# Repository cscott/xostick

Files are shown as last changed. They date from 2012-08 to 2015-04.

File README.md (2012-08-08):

This is a simple Open Hardware peripheral for the OLPC XO-1/1.5/1.75/4.

The files are created using Eagle 6.2.0 on Linux and the SparkFun
footprint libraries.

Some details about the design:

1. Supporting using either the ATtiny85 (lowest cost) or the ATtiny861
   (14 I/Os, slightly more expensive).
2. Based on the Sparkfun AVR Stick
    http://www.sparkfun.com/products/9147
   and thus software will be based on
    http://www.obdev.at/vusb/
   Note that the USB port has been moved to PB3/4 so software for the
   SparkFun AVR Stick will not work without modification.
3. The PCB we're working with is 0.8mm (0.031"); a USB plug "is supposed to be
   2.4mm (0.093") but you can get away with 1.6mm (0.062")" (thanks, djgpp)
   Our solution is to put two breakaway tabs on the back of the board.  You
   can break them off and glue them below the USB fingers to make it stay in
   the port better/at all.  One gotcha is that break away PCBs tend to stress
   nearby traces; I've tried to give them adequate clearance.  We're also
   putting copper fills on the PCBs to make them thicker (thanks again, djgpp).
   The PCB we have also has 4 layers, but I've routed this board with only
   the top and bottom so that 2 layer reproductions will work just fine as
   well.  The inner two layers are ground and power planes, which don't
   need to be present to connect the ground and power nets.
4. I'm attempting to bring BOM below $1/student and part count down as low as
   possible as well.  As a result, we're skimping a bit on ferrites and
   bypass caps.
5. There are pads for populating a mini USB B connector, so you can
   put this on a cable (and avoid the glue-the-PCBs-together dance).
6. The XO Stick has a standard arduino shield pinout.  This lets it be
   piggybacked on another XO Stick for programming, or piggy backed on
   an XOrduino to control a turtle robot.  Standard arduino shields will
   probably *not* work, since not all pins are connected -- but they might!
7. To program one XO Stick from an XOrduino, the RST header on the
   target should be put in the "PROG" position so that the programmer
   can drive it via arduino pin 0.  To program an XO Stick from another
   XO Stick, both RST headers should be in the "NORM" position, and
   the programmer needs to have the RSTDISBL fuse programmed, so that it
   can use PB5 ('85) or PB7 ('861) as an output.  Note that once RSTDISBL
   is programmed, the device can't be programmed using the ICSP port
   until RSTDISBL is unprogrammed using the high-voltage programming method.
8. The XO Stick currently needs an external programmer.
   Can we write a USB DFU bootloader using v-usb?
   Something like:

        http://www.obdev.at/products/vusb/usbasploader.html
        http://embedded-creations.com/projects/attiny85-usb-bootloader-overview/
        https://github.com/embedded-creations/USBaspLoader-tiny85

  -- C. Scott Ananian, 2012-06-09; revised 2012-07-30, 2012-08-08

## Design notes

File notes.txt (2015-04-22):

Notes on v14:
- LEDs should be labelled red/green in addition to LED1/LED2
- 10uF cap needs more space if XO Stick is to be used as shield
  (replaced with 6mm high cap in BOM, for $0.02 cost up)
- PROG/BOT header is too tight.  Vin header is ok?
- Vin and proto area vias should have larger pads
- pf says holes are in general too small for used parts.  make them
  all the same size as the proto area?
- measure tabs.  maybe too think now that there's solder resist and
  copper on it?
- add [outside] gnd, vcc, sig1, sig2 [inside] for mounting grove-style
  connectors? pgf wants [gnd, vcc, open] pattern somewhere for wiring
  connectors.

Notes on v9:
- usb connector up toward notch a little bit?  binding on bottom side.
  (moved 10 mil up for v10, chamfered bottom corner as well)

Notes on v5:

- ATtiny261A should be at least ATtiny461a if not ATtiny861a, since
  USB library takes up 2496 bytes.
- full size USB convert to mini or micro? (no through-hole micro-B connectors?)
- LED1/LED2 need better polarity mark
- use '-kit' suffixed versions of footprints (solder mask on component side)
- break off tab appears to work well.
- island between tabs should be anchored to body, not tabs?
- can we avoid anchors on break off tabs, instead use central anchor?
   ie.
     T
  ------------
 |            |
  --          \--
 TXT|            |
  --          \--
 |            |
  ------------
     T
where T indicates tabs.

- remove symmetry from USB connector placement to allow two tabs on
  XOrduino board.  (ie, move connector all the way down)
  (but retain 1.9" max width and spacing between USB port and edge to
  allow plugging XO Stick into vertical USB port on XO)

- J5/J6 should be normally-closed.

- EC programming header: 3.3v conversion (zeners?)
I was just looking at you pinout to check.  :)  Your pinout is close
but you don't have a chip select at all.  Its required for both the
EDI and talking to the SPI flash and there isn't a ground connection
in your pinout.

Look at the schematics in the dev docs cl4 directory. The same pinout
is used for both the EC EDI connection and the header for programming
the SPI flash.

Pin 1: MISO
Pin 2: Vcc (3.3V or NC for EC)
Pin 3: SCLK
Pin 4: MOSI
Pin 5: CS#
Pin 6: GND

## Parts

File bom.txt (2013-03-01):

Bill of Materials (v14)
Prices are from digikey, and in quantity 100.
---------------------------------------------

Required:
Part     Value            Device            Package              Library  DigiKey       Price (qty 100)
C1       10uF             CAP_POLPTH2       CPOL-RADIAL-10UF-25V SparkFun 493-5946-ND           $0.08020  (.06" lead spacing, 6mm tall)
C2       0.1uF            CAPPTH            CAP-PTH-SMALL        SparkFun 478-5741-ND           $0.09450 (.100" lead spacing)
D1       3V3              DIODE-ZENERPTH    DIODE-ZENER          SparkFun 1N5226BFSCT-ND        $0.072
D2       3V3              DIODE-ZENERPTH    DIODE-ZENER          SparkFun 1N5226BFSCT-ND        $0.072
R1       68               RESISTORAXIAL-0.3 AXIAL-0.3            SparkFun CF14JT68R0CT-ND	$0.02190 axial 0.3"
R2       68               RESISTORAXIAL-0.3 AXIAL-0.3            SparkFun CF14JT68R0CT-ND	$0.02190 axial 0.3"
R3       1.5K             RESISTORAXIAL-0.3 AXIAL-0.3            SparkFun CF14JT1K50CT-ND       $0.02190 axial 0.3"
U1       TINY85P          TINY85P           DIL08                atmel    ATTINY85-20PU-ND      $0.72 (instead of U2)
or
U2       TINY861A         TINY861P          DIL20                atmel    ATTINY861-20PU-ND     $1.75   (instead of U1)

Recommended I/O:
Part     Value            Device            Package              Library  DigiKey       Price (qty 100)
LED1     GREEN            LED3MM            LED3MM               SparkFun 754-1217-ND           $0.07150 3mm T1 green
LED2     RED              LED3MM            LED3MM               SparkFun 754-1218-ND           $0.07150 3mm T1 red
R4       470              RESISTORAXIAL-0.3 AXIAL-0.3            SparkFun CF14JT470RCT-ND       $0.02190 axial 0.3"
R5       470              RESISTORAXIAL-0.3 AXIAL-0.3            SparkFun CF14JT470RCT-ND       $0.02190 axial 0.3"
SW1      USER             TAC_SWITCHPTH     TACTILE-PTH          SparkFun 450-1652-ND           $0.1114  6mm

Optional:
Part     Value            Device            Package              Library  DigiKey       Price (qty 100)
H2       AVR_SPI_PRG_6PTH AVR_SPI_PRG_6PTH  2X3                  SparkFun 609-3218-ND           $0.1778
JP1/J1   RESET/POWER HEADER                 1x4, 1x4ish                   S1012EC-08-ND         $0.16950
U1 socket                                                                 AE9986-ND             $0.1196
U2 socket                                                                 AE9998-ND             $0.1911
X2 USB mini-B                                                             WM17115-ND            $1.1038
U3                                                                        497-7288-ND           $0.21000

Headers, to make a stackable or arduino-compatible board:

Part     Value       DigiKey      Price (qty 100)
H1       1x6         609-3558-ND  $0.6796
         1x8         609-3559-ND  $0.8791
         1x8         609-3559-ND  $0.8791
         1x10        609-3550-ND  $1.0657

(Note that digikey's prices for headers are quite steep.
SparkFun sells all four for $1.20 (quantity 100) at
  https://www.sparkfun.com/products/11417
which is substantially less than DigiKey, even though
SparkFun is selling at retail markup.  Presumably a large
deployment could get an even better wholesale price.
The DigiKey headers are also not stackable.)

----
Paste-able BOM for the required+recommended parts ('861 version):
(use https://ordering.digikey.com/registereduser/TextFileImport.aspx)

Required: (pick 1 of U1/U2)
1,493-5946-ND,C1 10uF
1,478-5741-ND,C2 0.1uF
2,1N5226BFSCT-ND,D1 D2 3.3V Zener
2,CF14JT68R0CT-ND,R1 R2 68 ohm
1,CF14JT1K50CT-ND,R3 1.5k ohm
1,ATTINY85-20PU-ND,U1
1,ATTINY861-20PU-ND,U2

Recommended:
1,754-1217-ND,LED1 T1 Green
1,754-1218-ND,LED2 T1 Red
2,CF14JT470RCT-ND,R4 R4 470 ohm
1,450-1652-ND,SW1 6mm

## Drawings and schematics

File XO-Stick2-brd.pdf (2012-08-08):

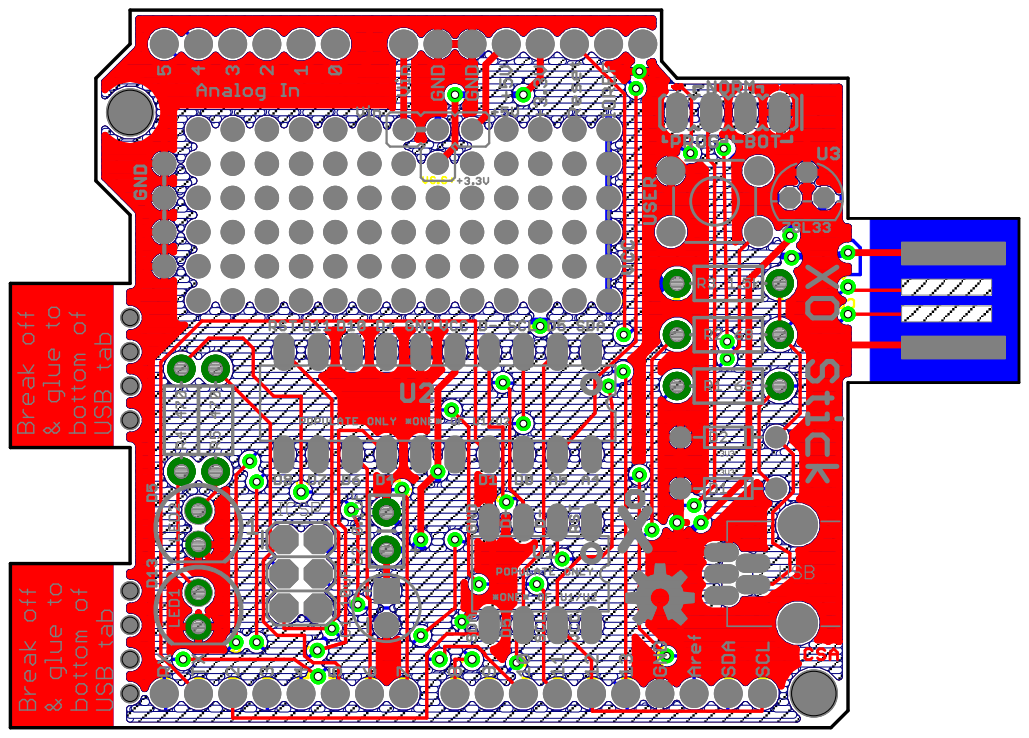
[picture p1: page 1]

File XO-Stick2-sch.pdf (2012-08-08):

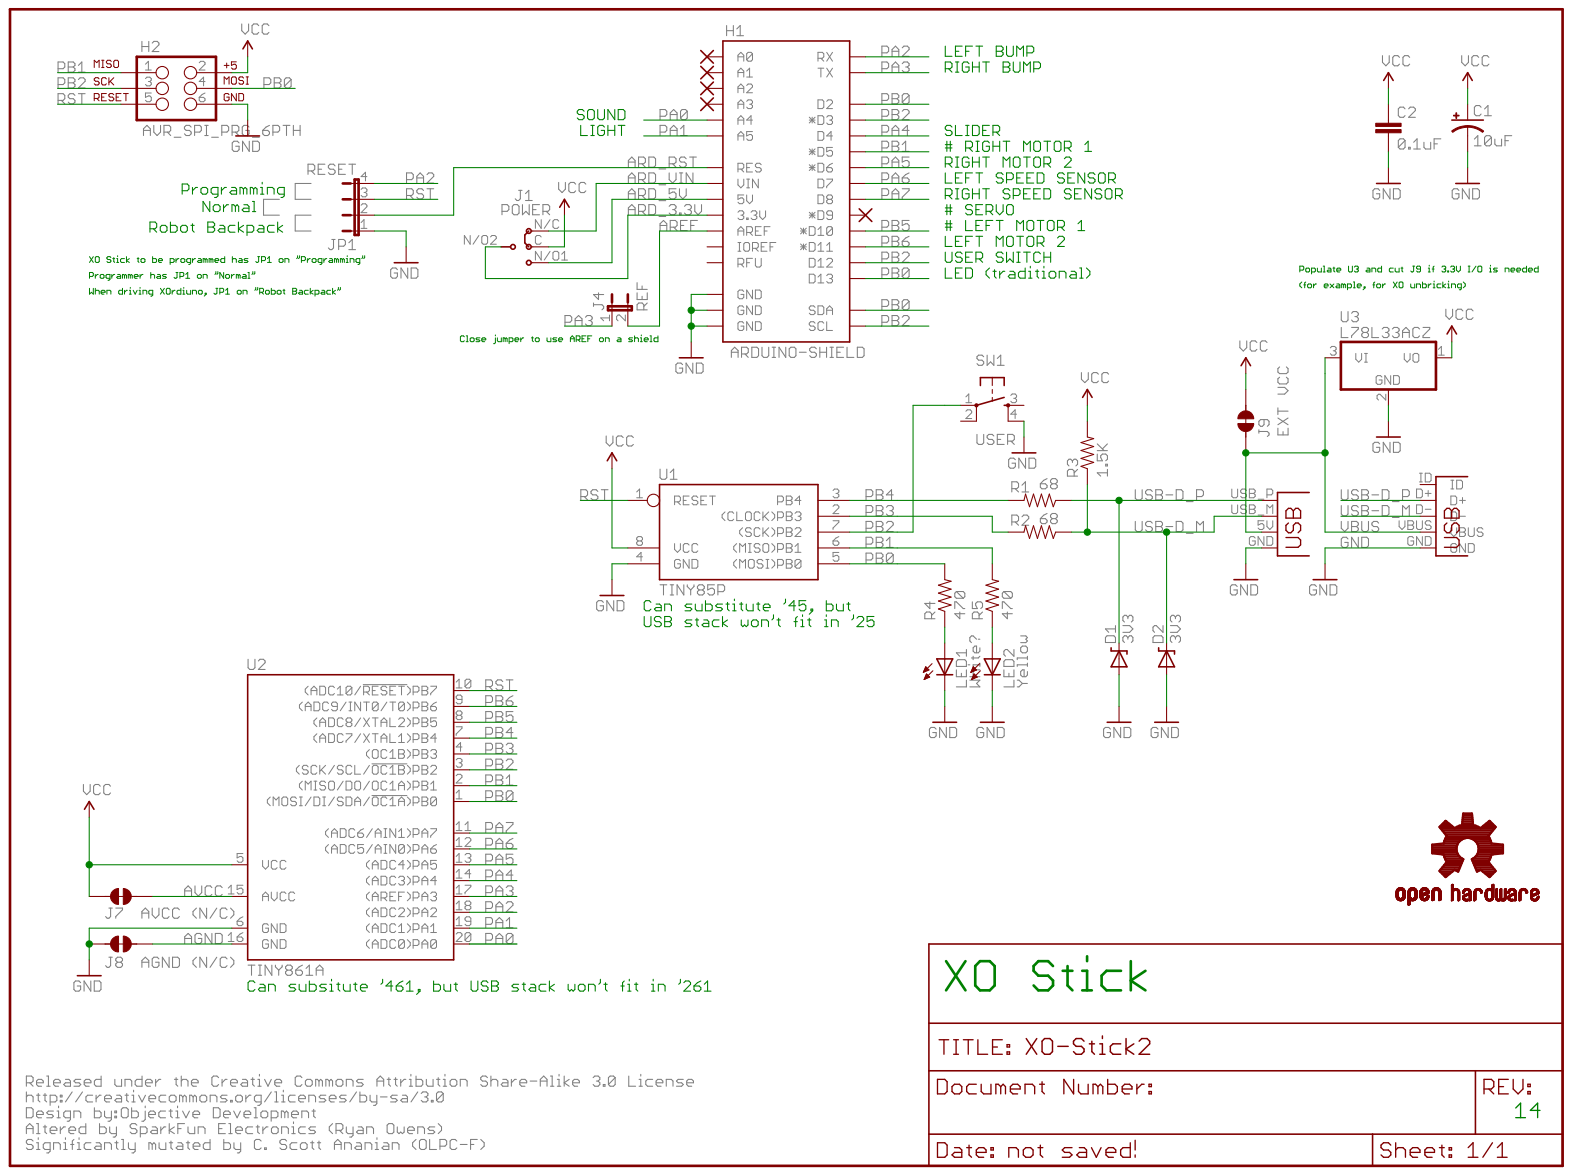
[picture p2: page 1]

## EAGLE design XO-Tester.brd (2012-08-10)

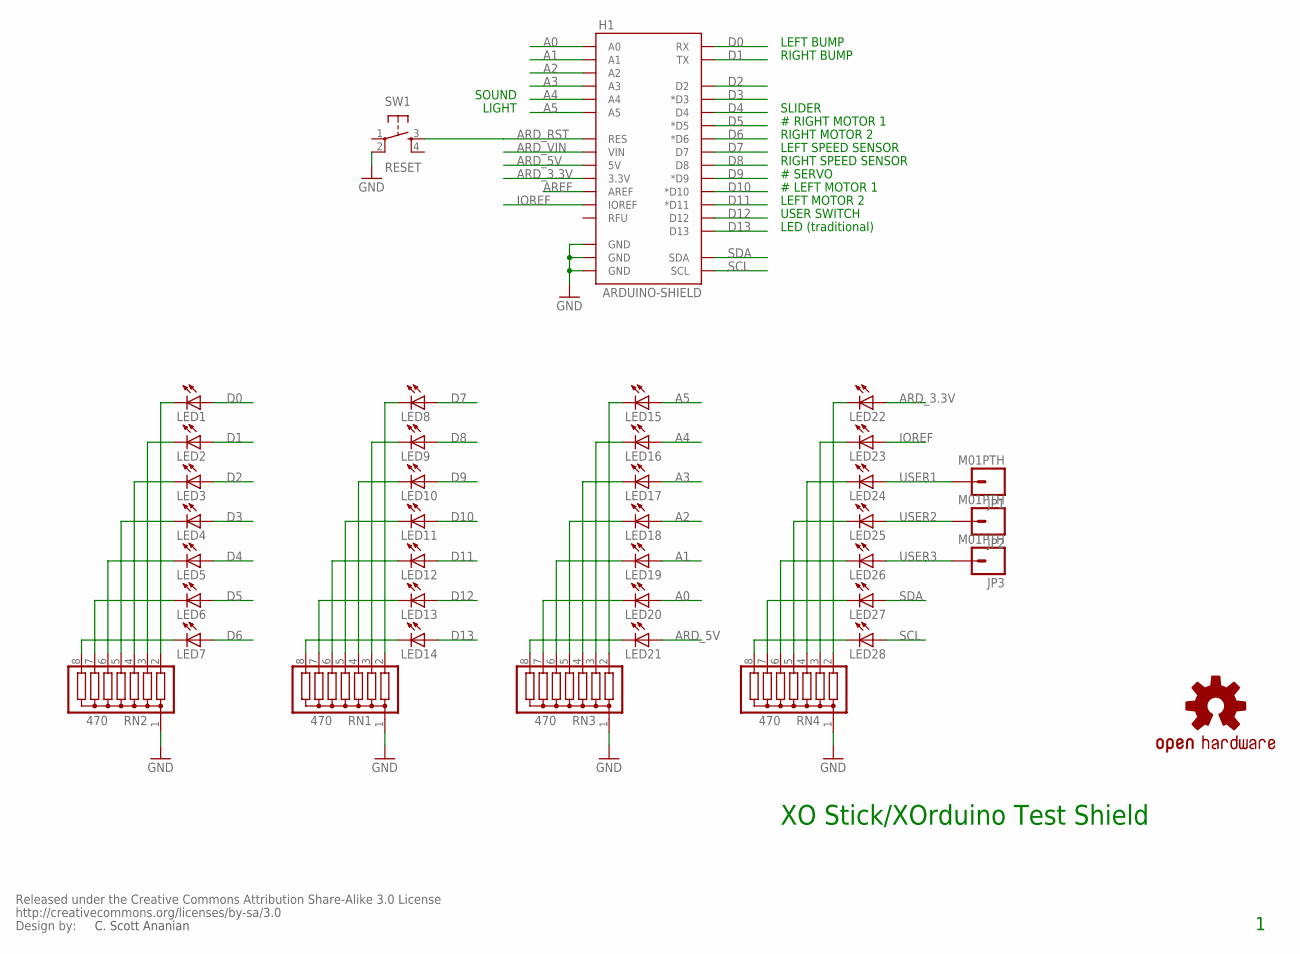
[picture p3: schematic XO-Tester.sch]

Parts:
H1: ARDUINO-SHIELD; ARDUINO-SHIELD-VIAS-HOLES
JP1, JP2, JP3: M01PTH; 1X01
LED1, LED2, LED3, LED4, LED5, LED6, LED7, LED8, LED9, LED10, LED11, LED12, LED13, LED14, LED15, LED16, LED17, LED18, LED19, LED20, LED21, LED22, LED23, LED24, LED25, LED26, LED27, LED28: LED3MM-KIT
RN1, RN2, RN3, RN4: 470; SIL8
SW1: RESET; TACTILE-PTH
U$1: OSHW-LOGOM; OSHW-LOGO-M
U$4: CREATIVE_COMMONS

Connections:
A0: H1.A0, LED20.A
A1: H1.A1, LED19.A
A2: H1.A2, LED18.A
A3: H1.A3, LED17.A
A4: H1.A4, LED16.A
A5: H1.A5, LED15.A
ARD_3.3V: H1.3.3V, LED22.A
ARD_5V: H1.5V, LED21.A
ARD_RST: H1.RES, SW1.3
ARD_VIN: H1.VIN
AREF: H1.AREF
D0: H1.RX, LED1.A
D1: H1.TX, LED2.A
D2: H1.D2, LED3.A
D3: H1.D3 (*D3), LED4.A
D4: H1.D4, LED5.A
D5: H1.D5 (*D5), LED6.A
D6: H1.D6 (*D6), LED7.A
D7: H1.D7, LED8.A
D8: H1.D8, LED9.A
D9: H1.D9 (*D9), LED10.A
D10: H1.D10 (*D10), LED11.A
D11: H1.D11 (*D11), LED12.A
D12: H1.D12, LED13.A
D13: H1.D13, LED14.A
GND: H1.GND@0 (GND), H1.GND@1 (GND), H1.GND@2 (GND), RN1.1, RN2.1, RN3.1, RN4.1, SW1.2
IOREF: H1.IOREF, LED23.A
unnamed: LED8.K (C), RN1.2
unnamed: LED9.K (C), RN1.3
unnamed: LED1.K (C), RN2.2
unnamed: LED2.K (C), RN2.3
unnamed: LED3.K (C), RN2.4
unnamed: LED4.K (C), RN2.5
unnamed: LED5.K (C), RN2.6
unnamed: LED6.K (C), RN2.7
unnamed: LED7.K (C), RN2.8
unnamed: LED10.K (C), RN1.4
unnamed: LED11.K (C), RN1.5
unnamed: LED12.K (C), RN1.6
unnamed: LED13.K (C), RN1.7
unnamed: LED14.K (C), RN1.8
unnamed: LED15.K (C), RN3.2
unnamed: LED16.K (C), RN3.3
unnamed: LED17.K (C), RN3.4
unnamed: LED18.K (C), RN3.5
unnamed: LED19.K (C), RN3.6
unnamed: LED20.K (C), RN3.7
unnamed: LED21.K (C), RN3.8
unnamed: LED22.K (C), RN4.2
unnamed: LED23.K (C), RN4.3
unnamed: LED24.K (C), RN4.4
unnamed: LED25.K (C), RN4.5
unnamed: LED26.K (C), RN4.6
unnamed: LED27.K (C), RN4.7
unnamed: LED28.K (C), RN4.8
SCL: H1.SCL, LED28.A
SDA: H1.SDA, LED27.A
USER1: JP1.1, LED24.A
USER2: JP2.1, LED25.A
USER3: JP3.1, LED26.A

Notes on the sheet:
C. Scott Ananian
XO Stick/XOrduino Test Shield
# RIGHT MOTOR 1
# SERVO
# LEFT MOTOR 1
LEFT BUMP
RIGHT BUMP
SLIDER
RIGHT MOTOR 2
LEFT SPEED SENSOR
RIGHT SPEED SENSOR
LEFT MOTOR 2
USER SWITCH
LED (traditional)
SOUND
LIGHT

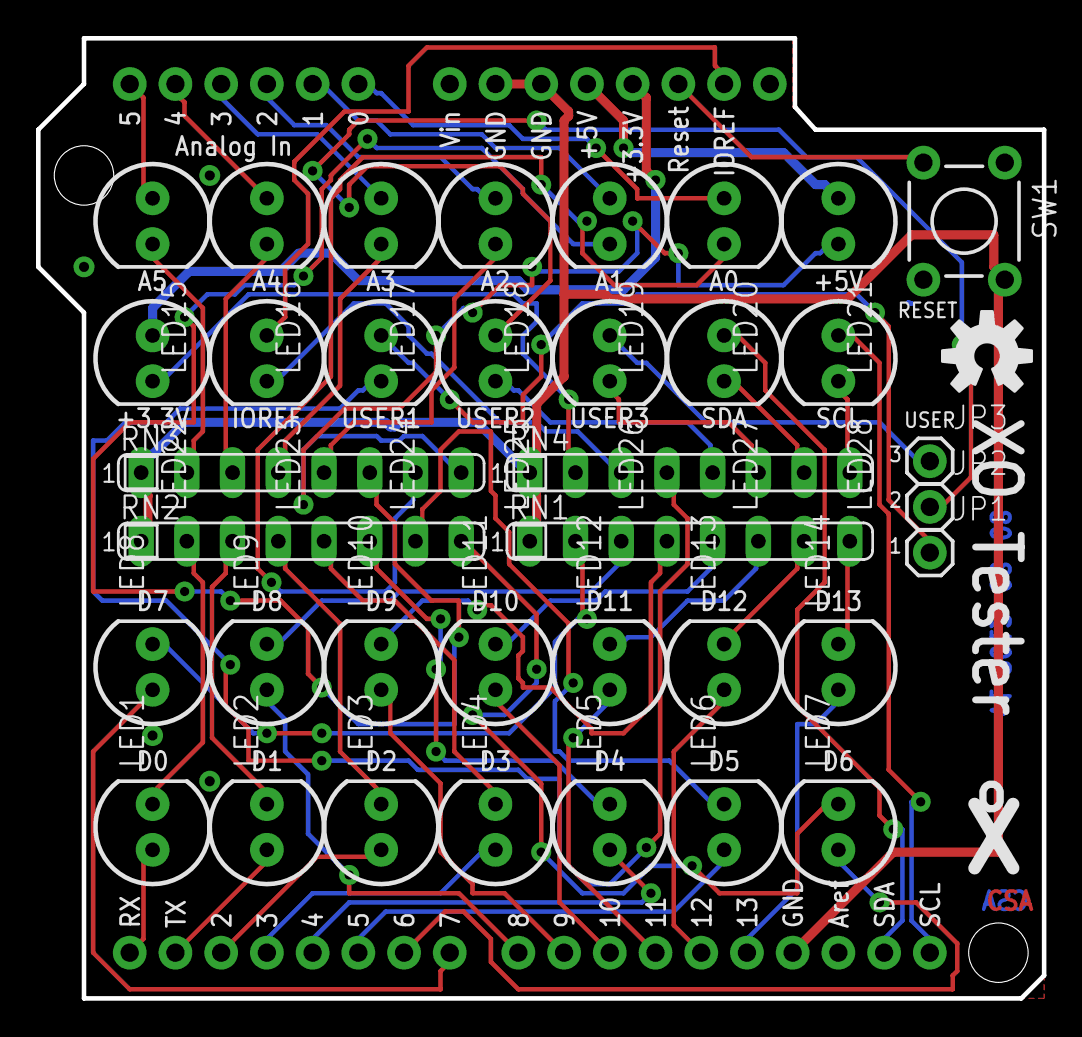
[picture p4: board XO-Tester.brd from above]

Board: 2 copper layers, 55.9 x 53.3 mm, 39 parts (0 on the bottom side), 58 nets.

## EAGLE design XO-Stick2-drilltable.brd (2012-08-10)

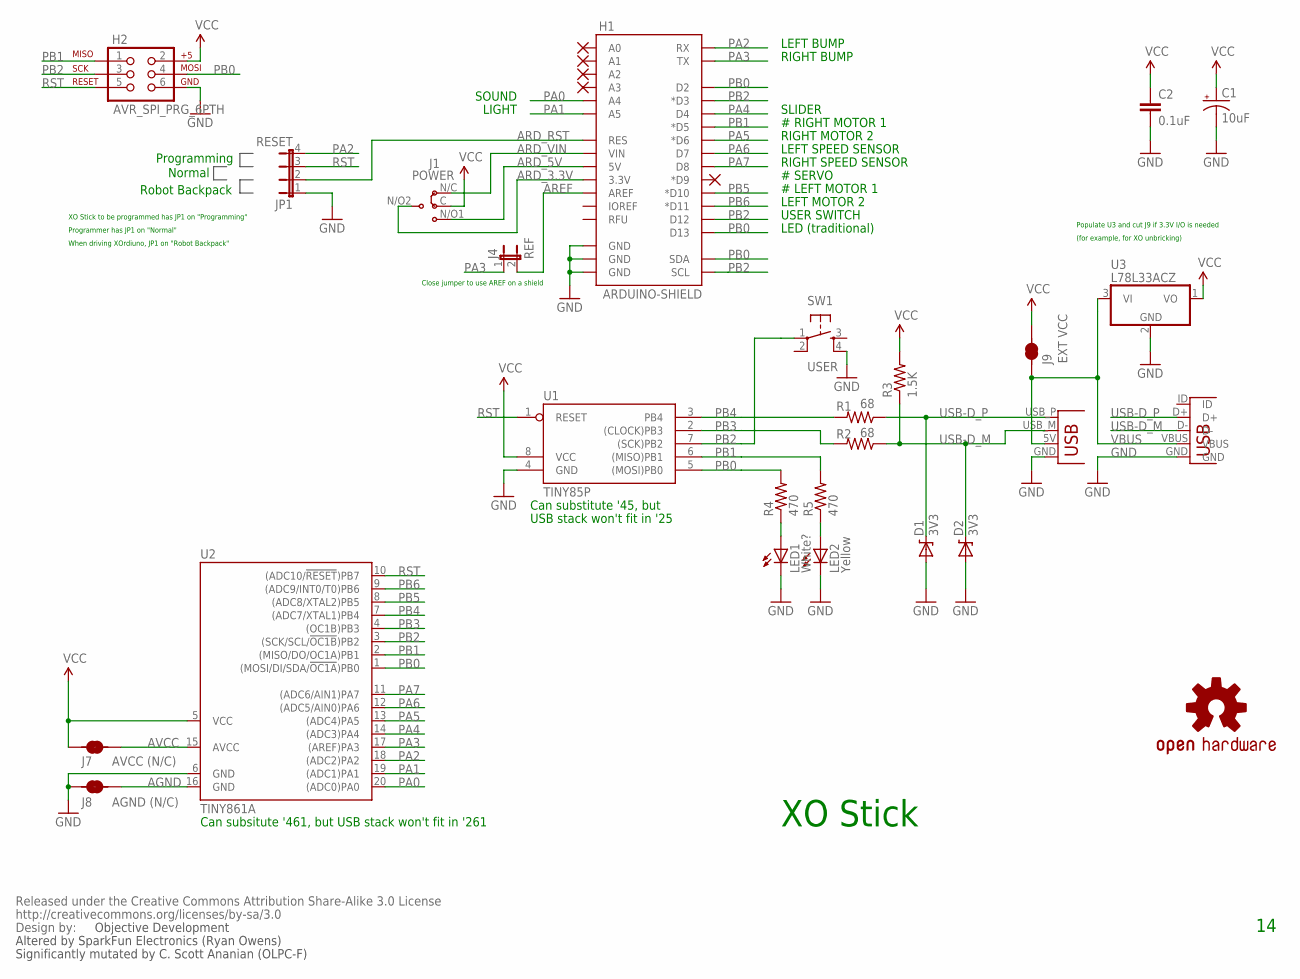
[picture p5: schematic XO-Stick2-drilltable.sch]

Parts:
C1: 10uF; CPOL-RADIAL-10UF-25V
C2: 0.1uF; CAP-PTH-SMALL-KIT
D1, D2: 3V3; DIODE-ZENER
H1: ARDUINO-SHIELD; ARDUINO-SHIELD-VIAS-HOLES
H2: AVR_SPI_PRG_6PTH; 2X3
J1: POWER; JP4-TRACE-NOCONFLICT
J4: REF; SJ-2S-NO
J7: AVCC (N/C); SJ-2S-BOT-TRACE-NOCONFLICT
J8: AGND (N/C); SJ-2S-BOT-TRACE-NOCONFLICT
J9: EXT VCC; SJ-2S-BOT-TRACE-NOCONFLICT-PAD
JP1: RESET; JP4
LED1: White?; LED3MM-KIT
LED2: Yellow; LED3MM-KIT
R1, R2: 68; AXIAL-0.3-KIT
R3: 1.5K; AXIAL-0.3-KIT
R4, R5: 470; AXIAL-0.3-KIT
SW1: USER; TACTILE-PTH
U1: TINY85P; DIL08
U2: TINY861A; DIL20
U3: L78L33ACZ; TO92
U$1: OSHW-LOGOM; OSHW-LOGO-M
U$4: CREATIVE_COMMONS
X1: USBPCB; USB-A-PCB
X2: USBMINIB; USB-MB-H2

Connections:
AGND: J8.2, U2.16 (GND)
ARD_3.3V: H1.3.3V, J1.N/O2
ARD_5V: H1.5V, J1.N/O1
ARD_RST: H1.RES, JP1.2
ARD_VIN: H1.VIN, J1.N/C
AREF: H1.AREF, J4.2
AVCC: J7.2, U2.15 (AVCC)
GND: C1.2 (-), C2.2, D1.P$2 (A), D2.P$2 (A), H1.GND@0 (GND), H1.GND@1 (GND), H1.GND@2 (GND), H2.6, J8.1, JP1.1, LED1.K (C), LED2.K (C), SW1.4, U1.4 (GND), U2.6 (GND), U3.2 (GND), X1.GND, X2.GND
unnamed: LED1.A, R4.P$1 (1)
unnamed: LED2.A, R5.P$1 (1)
PA0: H1.A4, U2.20 ((ADC0)PA0)
PA1: H1.A5, U2.19 ((ADC1)PA1)
PA2: H1.RX, JP1.4, U2.18 ((ADC2)PA2)
PA3: H1.TX, J4.1, U2.17 ((AREF)PA3)
PA4: H1.D4, U2.14 ((ADC3)PA4)
PA5: H1.D6 (*D6), U2.13 ((ADC4)PA5)
PA6: H1.D7, U2.12 ((ADC5/AIN0)PA6)
PA7: H1.D8, U2.11 ((ADC6/AIN1)PA7)
PB0: H1.D2, H1.D13, H1.SDA, H2.4, R4.P$2 (2), U1.5 ((MOSI)PB0), U2.1 ((MOSI/DI/SDA/!OC1A!)PB0)
PB1: H1.D5 (*D5), H2.1, R5.P$2 (2), U1.6 ((MISO)PB1), U2.2 ((MISO/DO/OC1A)PB1)
PB2: H1.D3 (*D3), H1.D12, H1.SCL, H2.3, SW1.1, U1.7 ((SCK)PB2), U2.3 ((SCK/SCL/!OC1B!)PB2)
PB3: R2.P$2 (2), U1.2 ((CLOCK)PB3), U2.4 ((OC1B)PB3)
PB4: R1.P$2 (2), U1.3 (PB4), U2.7 ((ADC7/XTAL1)PB4)
PB5: H1.D10 (*D10), U2.8 ((ADC8/XTAL2)PB5)
PB6: H1.D11 (*D11), U2.9 ((ADC9/INT0/T0)PB6)
RST: H2.5, JP1.3, U1.1 (RESET), U2.10 ((ADC10/!RESET!)PB7)
USB-D_M: D2.P$1 (C), R2.P$1 (1), R3.P$1 (1), X1.USB_M (D-), X2.D-
USB-D_P: D1.P$1 (C), R1.P$1 (1), X1.USB_P (D+), X2.D+
VBUS: J9.1, U3.3 (VI), X1.5V (VBUS), X2.VBUS
VCC: C1.1 (+), C2.1, H2.2, J1.C, J7.1, J9.2, R3.P$2 (2), U1.8 (VCC), U2.5 (VCC), U3.1 (VO)

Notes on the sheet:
Objective Development
Altered by SparkFun Electronics (Ryan Owens)
XO Stick
# RIGHT MOTOR 1
# SERVO
# LEFT MOTOR 1
LEFT BUMP
RIGHT BUMP
SLIDER
RIGHT MOTOR 2
LEFT SPEED SENSOR
RIGHT SPEED SENSOR
LEFT MOTOR 2
USER SWITCH
LED (traditional)
SOUND
LIGHT
Significantly mutated by C. Scott Ananian (OLPC-F)
Programming
Robot Backpack
Normal
XO Stick to be programmed has JP1 on "Programming"
Programmer has JP1 on "Normal"
When driving XOrdiuno, JP1 on "Robot Backpack"
Close jumper to use AREF on a shield
Can subsitute '461, but USB stack won't fit in '261
Can substitute '45, but
USB stack won't fit in '25
Populate U3 and cut J9 if 3.3V I/O is needed
(for example, for XO unbricking)

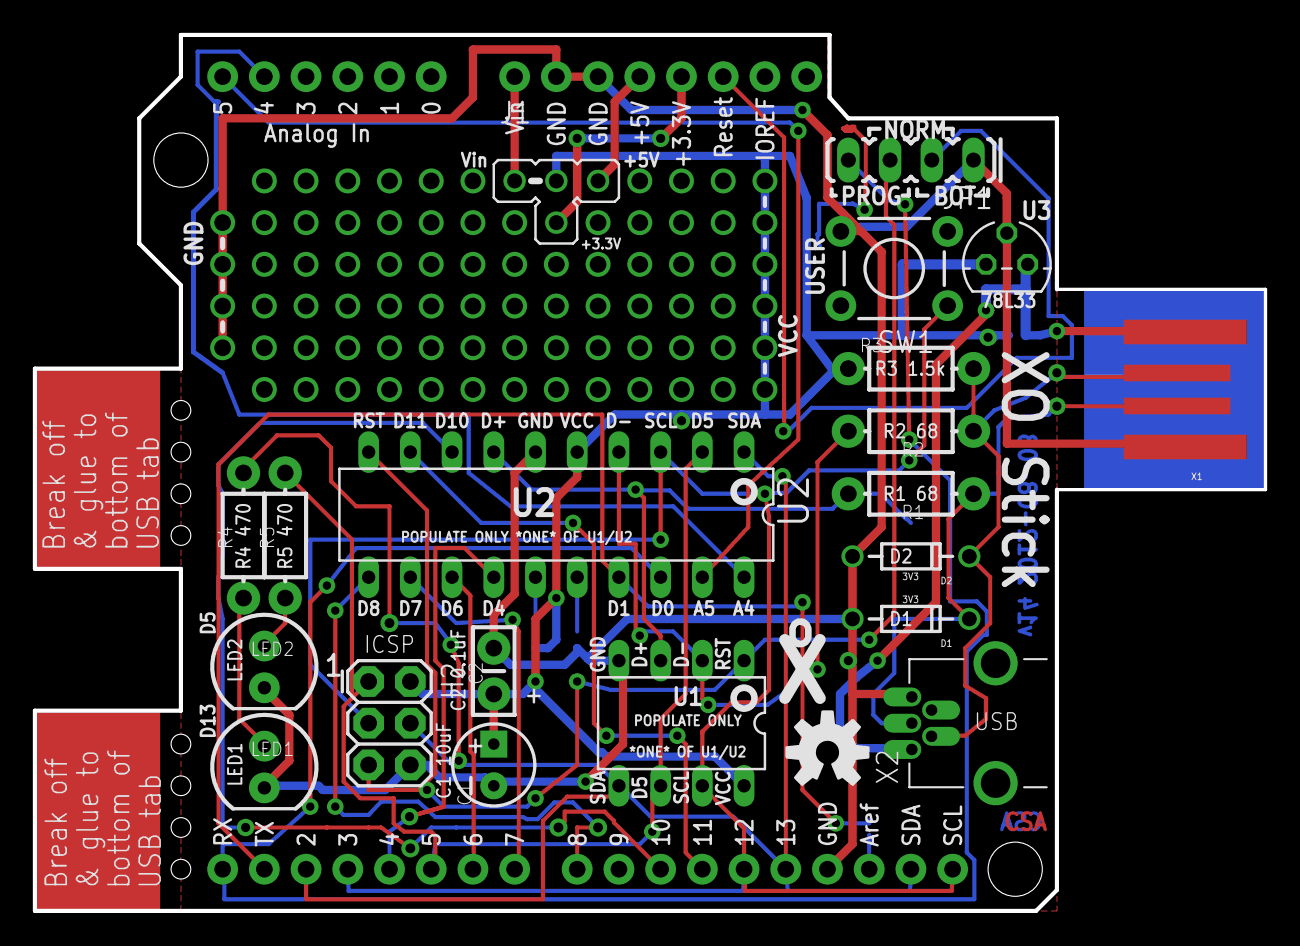
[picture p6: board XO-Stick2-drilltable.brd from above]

Board: 2 copper layers, 74.9 x 53.3 mm, 28 parts (1 on the bottom side), 30 nets.

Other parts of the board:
DRILEGEND: DRILEGEND

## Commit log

2012-06-05 SparkFun version of AVR Stick.
    [AVR-Stick-v12.brd, AVR-Stick-v12.sch]
2012-06-05 ATtiny261/ATtiny85 version, w/ new headers, not routed.
    [AVR-Stick-v12.brd, AVR-Stick-v12.sch]
2012-06-05 Routed v1 of the XO stick layout.
    [AVR-Stick-v12.brd, AVR-Stick-v12.sch]
2012-06-06 2012-06-07 version of XO stick: add USB mini-B, switch, zeners.
    [AVR-Stick-v12.brd, AVR-Stick-v12.sch]
2012-06-06 v3: tweak dimensions for better fit on XO, switch to 3mm LED, add silkscreen.
    [AVR-Stick-v12.brd, AVR-Stick-v12.sch]
2012-06-06 v4: thicker power/gnd traces, add fill to backside of USB conn for thickness.
    [AVR-Stick-v12.brd, AVR-Stick-v12.sch]
2012-06-06 v5: add ground and VCC planes.
    [AVR-Stick-v12.brd, AVR-Stick-v12.sch]
2012-06-09 Rename files from AVR-Stick to XO-Stick.
    [XO-Stick.brd, XO-Stick.sch]
2012-06-10 Update BOM w/ digikey part #s.
2012-06-20 Add gerbers for 4 layer PCB, just in case that's useful.
2012-07-18 Check-in assembly notes from A1 build of XO Stick.
2012-07-28 v6 of schematic: add xorduino compatible shields, prototype area.
    Too many selectable headers in this version, need to trim some for space.
    Also, we need to move the USB connector in order to nest tightly with
    XOrduino board.
    [XO-Stick.brd, XO-Stick.sch]
2012-07-30 v7 of board/schematic. Fixed remaining issues with v6. 2-layer routing.
    [XO-Stick.brd, XO-Stick.sch]
2012-07-30 Remove old v5 gerbers to avoid confusion.
2012-07-31 XO Stick v8: add jumper between VBUS and VCC; make SDA/SCL jumpers N/C.
    SDA and SCL jumpers need to be closed in order to program XO Stick from
    an XOrduino. Splitting VBUS from VCC is needed in order to make a 3.3v
    variant XO Stick for XO unbricking.
    [XO-Stick.brd, XO-Stick.sch]
2012-07-31 XO Stick v9: add silkscreen to break-off tabs, move some traces.
    Moved traces away from break-off tabs and removed one trace from the
    top side of the USB connector.
    [XO-Stick.brd, XO-Stick.sch]
2012-07-31 XO Stick v10: moved USB connector up 10 mil to better fit vertical XO port.
    [XO-Stick.brd, XO-Stick.sch]
2012-07-31 Tweak USB mini-B connector footprint; restring to 8mil min.
    USB connector footprint was restricting the min pad width in our restring.
    Noticed that USB footprint was really loose, too. Checked against datasheet,
    tightened up holes and switched to oblong pads. Restring to 8mil min,
    which required a few minor trace adjustments.
    [XO-Stick.brd, XO-Stick.sch]
2012-08-01 Add optional 3.3v TO-92 LDO regulator, for use when unbricking XOs.
    [XO-Stick.brd, XO-Stick.sch]
2012-08-03 XO Stick v13: silkscreen additions; rename nets in schematic for less confusion.
    [XO-Stick.brd, XO-Stick.sch]
2012-08-08 Minor tweak to schematic: swap SCL/SDA signals to match their order on the PCB.
    [XO-Stick.sch]
2012-08-08 XO Stick v14: move USB to PB3/4 (Louis Beaudoin suggestion).
    This allows more straightforward use of the XO Stick as a programmer,
    and of the XO Stick's I2C bus.
    It complicates use of the '85 to drive the XOrduino bot, but that's probably
    a reasonable sacrifice.
    [XO-Stick2.brd, XO-Stick2.sch]
2012-08-08 Add a simple Arduino shield to aid in testing XO Stick and XOrduino.
    [XO-Tester.brd, XO-Tester.sch]
2012-08-10 Add drill table layer; regenerate Gerbers in vendor-approved format.
    The drill table was made with drillegend-stack.ulp. It has a problem deleting
    an existing drill table (see
    http://www.eaglecentral.ca/forums/index.php/mv/msg/46577/145423/
    ) so I've saved the .brd file with the drill legend as XO-Stick2-drilltable.brd.
    If changes are necessary to XO-Stick2.brd, regenerate XO-Stick2-drilltable.brd
    from XO-Stick2.brd after making the changes.
    [XO-Stick2-drilltable.brd, XO-Stick2-drilltable.sch]
2012-08-10 Gerbers for the test shield.
    [XO-Tester.brd]
2013-03-01 Update BOM and assembly notes for XO Stick v14.
2013-03-01 Add cut-and-pasteable BOM for easier ordering from DigiKey.

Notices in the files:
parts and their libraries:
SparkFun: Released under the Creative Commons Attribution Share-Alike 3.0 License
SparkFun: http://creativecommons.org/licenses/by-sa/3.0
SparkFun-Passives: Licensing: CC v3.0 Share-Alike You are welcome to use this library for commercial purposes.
